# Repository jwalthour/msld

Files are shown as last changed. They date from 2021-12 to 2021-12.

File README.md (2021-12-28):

# Multi-Sport LED display

## Credits
A huge thanks to the following:
* ESPN.com for making an openly accessible sports data API that enables all these projects
* Github user mikemountain for NFL support and my original inspiration: https://github.com/mikemountain/nfl-led-scoreboard
* Github user riffnshred on whose work mikemountain's was based: https://github.com/riffnshred/nhl-led-scoreboard
* Github developers who wrote the MLB LED scoreboard on which all the above are based: https://github.com/MLB-LED-Scoreboard/mlb-led-scoreboard
* Github user hzeller for the RGB matrix driver: https://github.com/hzeller/rpi-rgb-led-matrix/

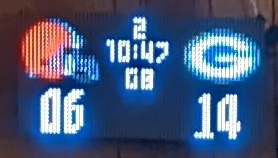
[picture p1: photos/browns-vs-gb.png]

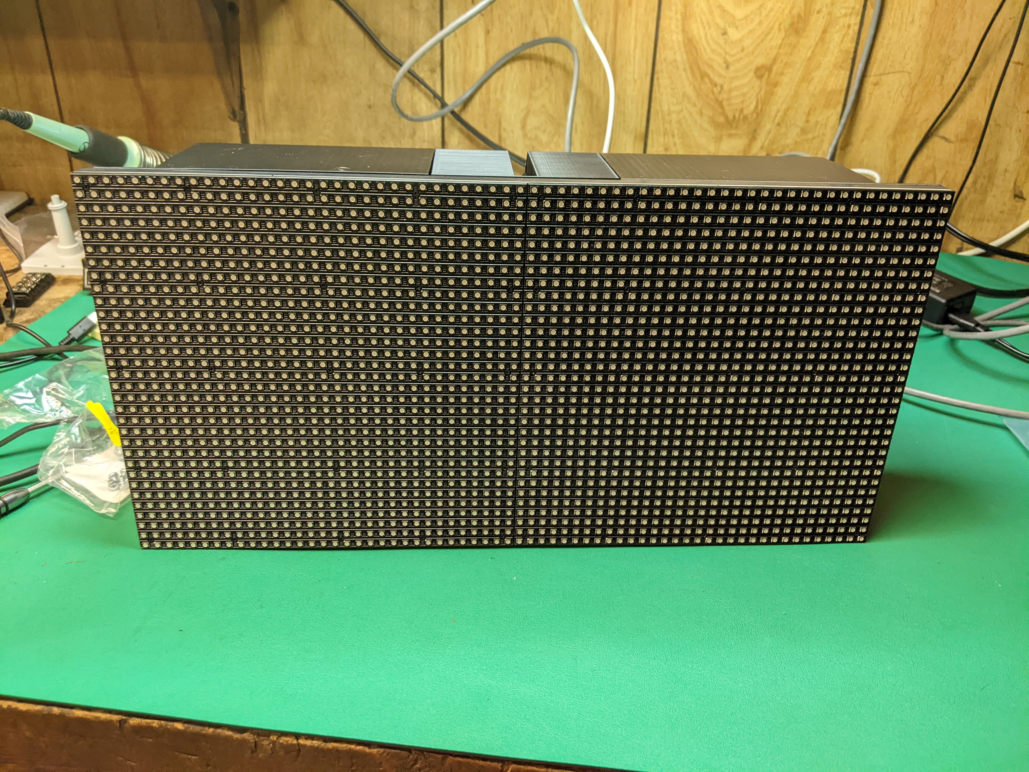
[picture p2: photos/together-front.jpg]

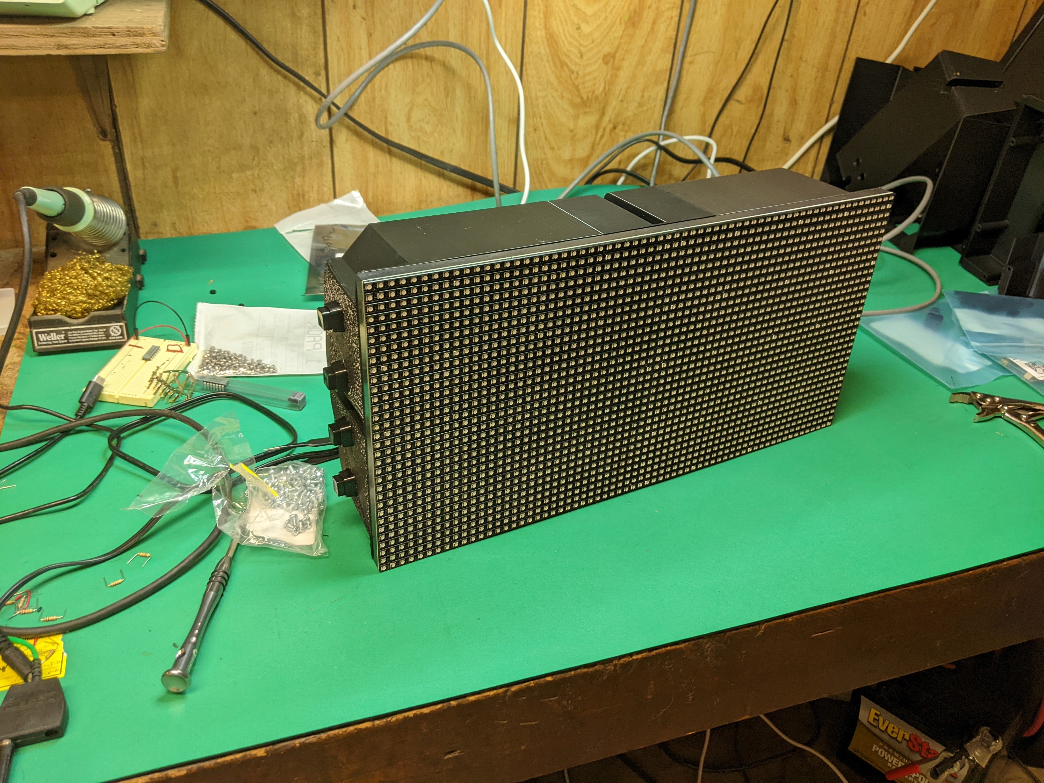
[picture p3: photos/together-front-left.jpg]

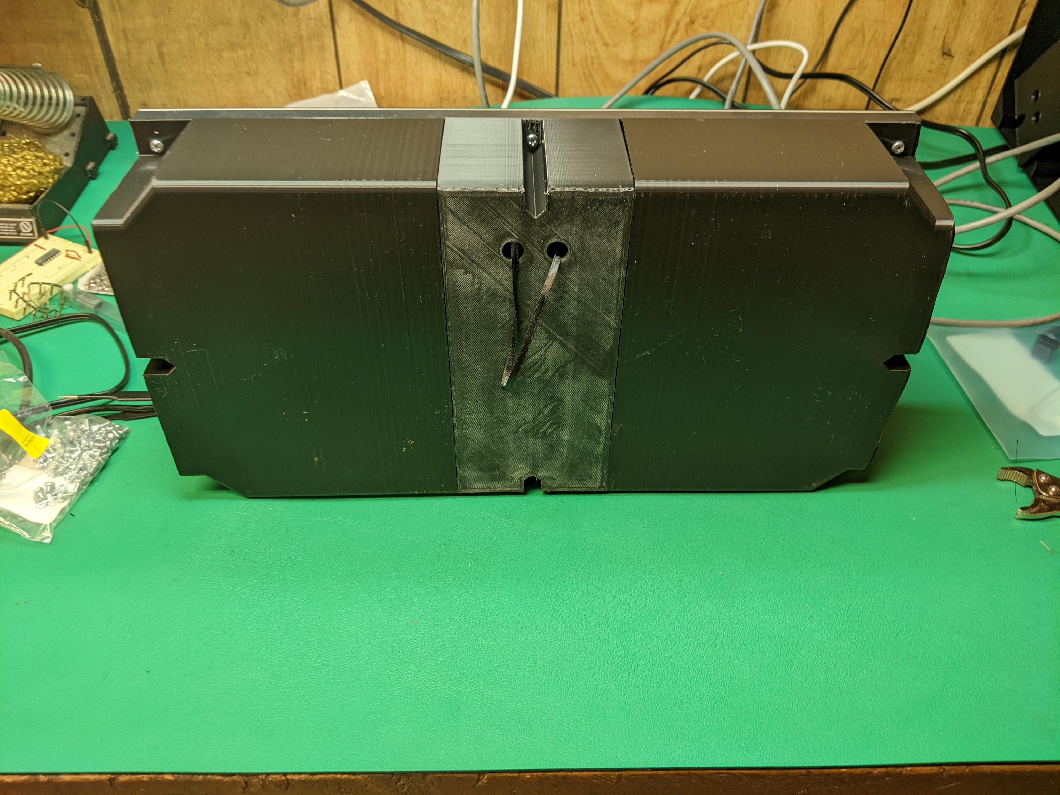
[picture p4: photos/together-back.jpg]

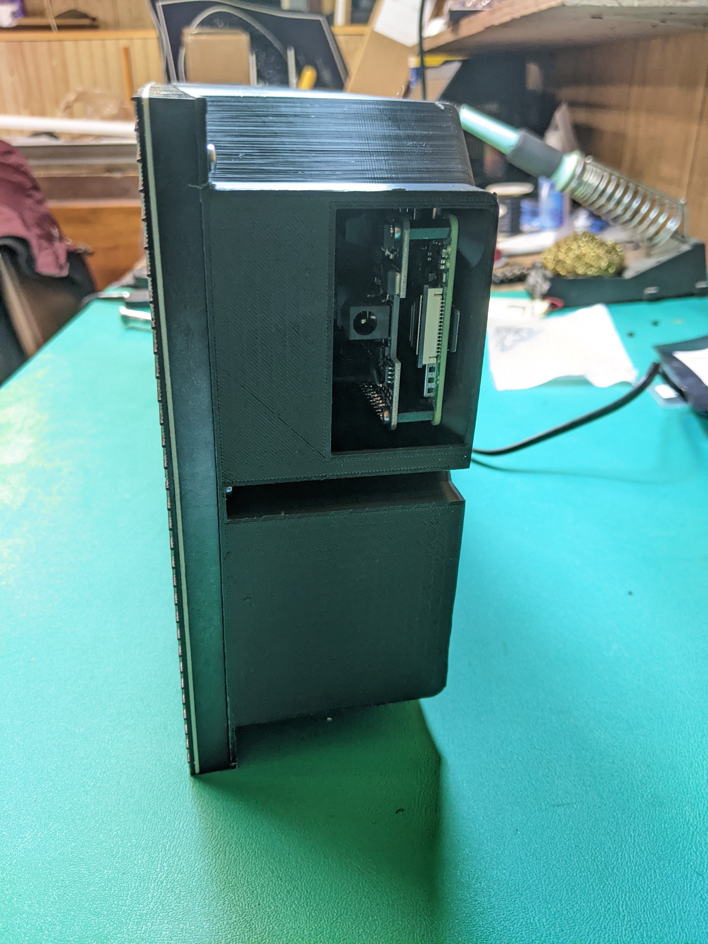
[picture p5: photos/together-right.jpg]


## How to build your own

[Electrical](electrical/Electrical.md)

[Mechanical](mechanical/Mechanical.md)

[Software](Installation.md)

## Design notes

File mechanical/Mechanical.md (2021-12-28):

# Printing and assembly

## Printing

The backshell prints in three parts: left, right, and center.  These are from the viewer's perspective - "left" has the button holes, "right" has the Pi.  STL files for all three are found in this directory.

Print settings I used common to all three parts:
* PLA
* 0.4mm nozzle
* 1.05mm wall thickness (maybe do thicker - it's important for the threaded inserts to grab onto something)
* 40% infill, gyroid (made this higher than default to strengthen the parts)
* 6 top layers, 6 bottom layers
* Brim adhesion
* Coasting off
* 200°C extruder
* 60°C bed
* 15mm/s initial speed
* 50mm/s final speed

Print the left and right sides with no supports, and their alignment pins facing upward.  You won't be able to remove supports from the holes for the threaded inserts, so definitely do not use supports.

The screenshot below shows both the left and right sides together as one print.  I don't recommend this, as it adds about a day to the overall printing.

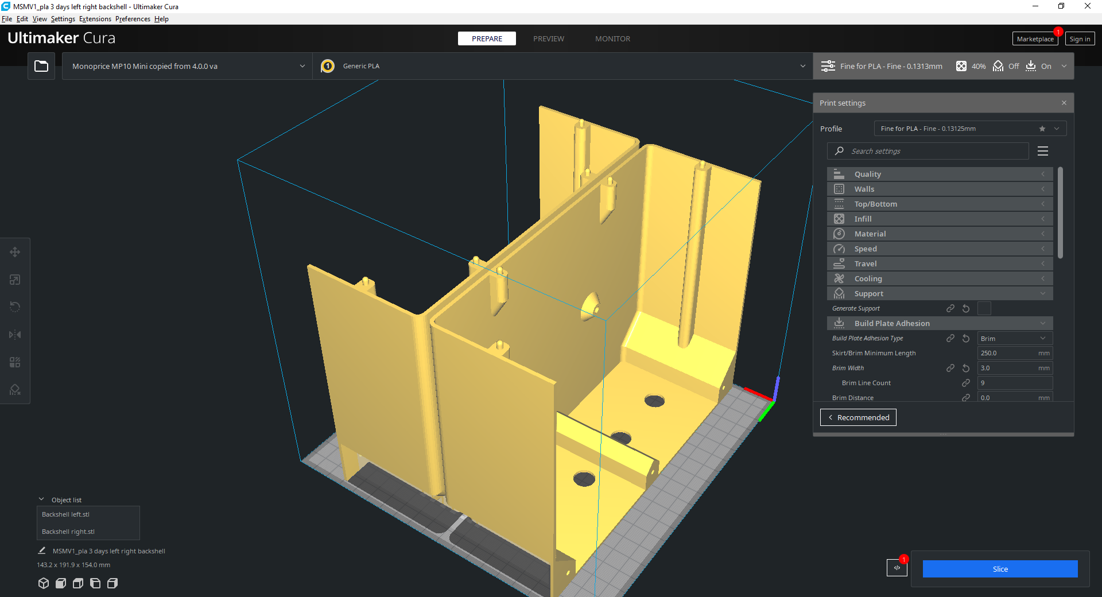
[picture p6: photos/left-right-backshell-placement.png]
left and right backshell orientation


1. Print the center side with supports on and the large rib upward (the "inside" up).

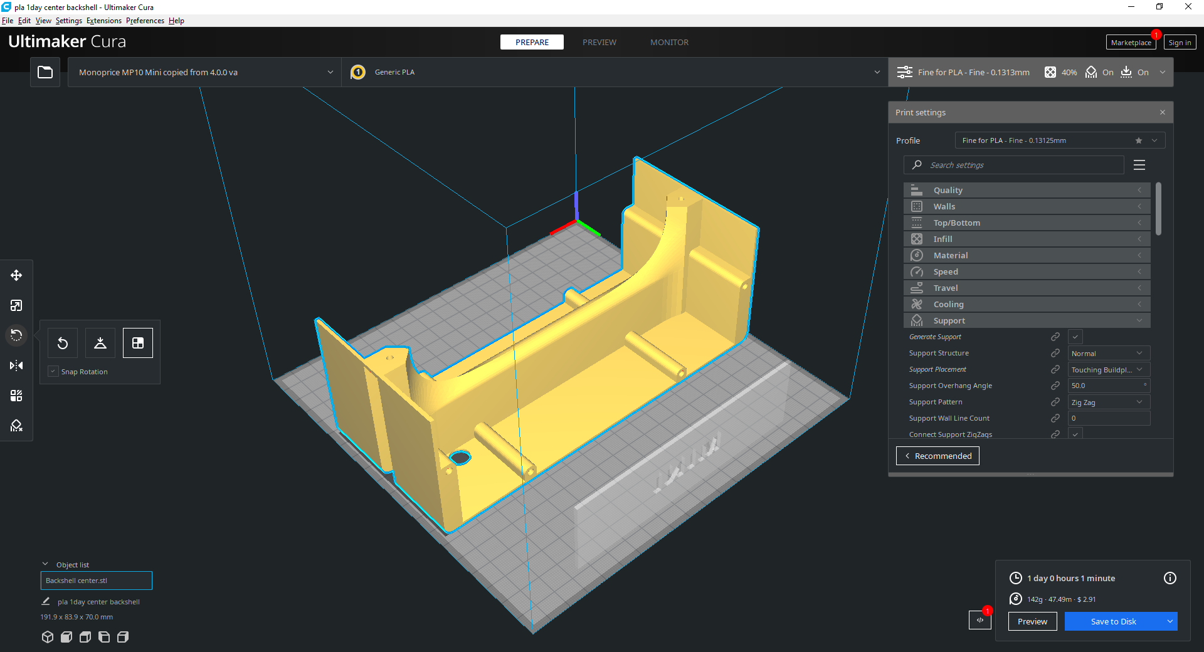
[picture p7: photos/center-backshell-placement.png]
center backshell orientation


Each of the parts is about a 1 day print.

## Assembly

Install the threaded inserts by setting your soldering iron to about 400°F and gently melting them down in.  You need 4 for the pi and 2 for the perma proto board.

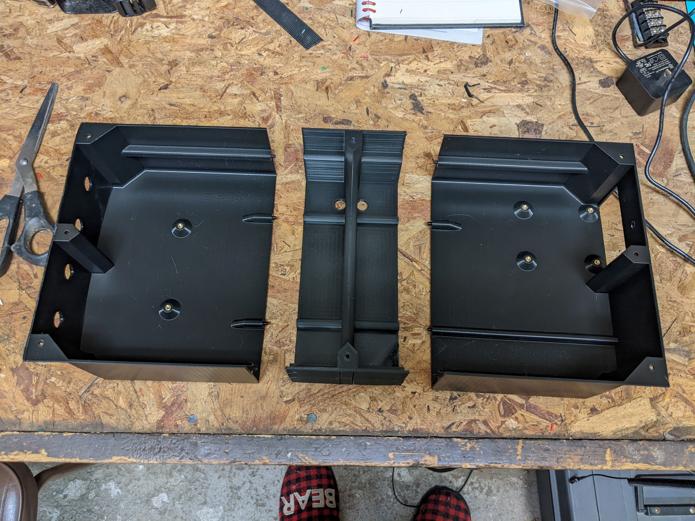
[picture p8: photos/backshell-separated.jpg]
Backshell after installing threaded inserts


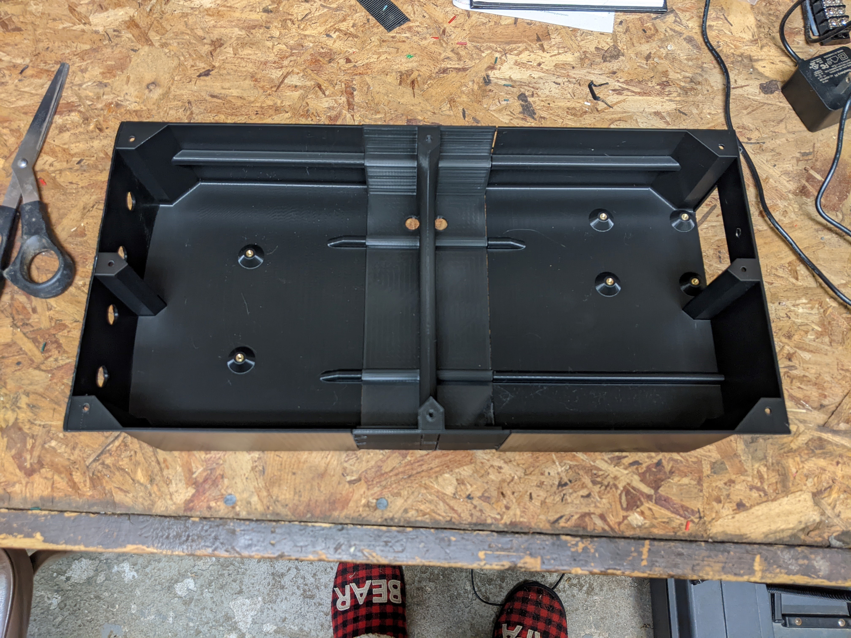
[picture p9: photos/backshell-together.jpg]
Backshell fit together


If you want to hang the display on the wall, tie about a 6" length of ribbon (or string, or wire) through the holes in the center piece.

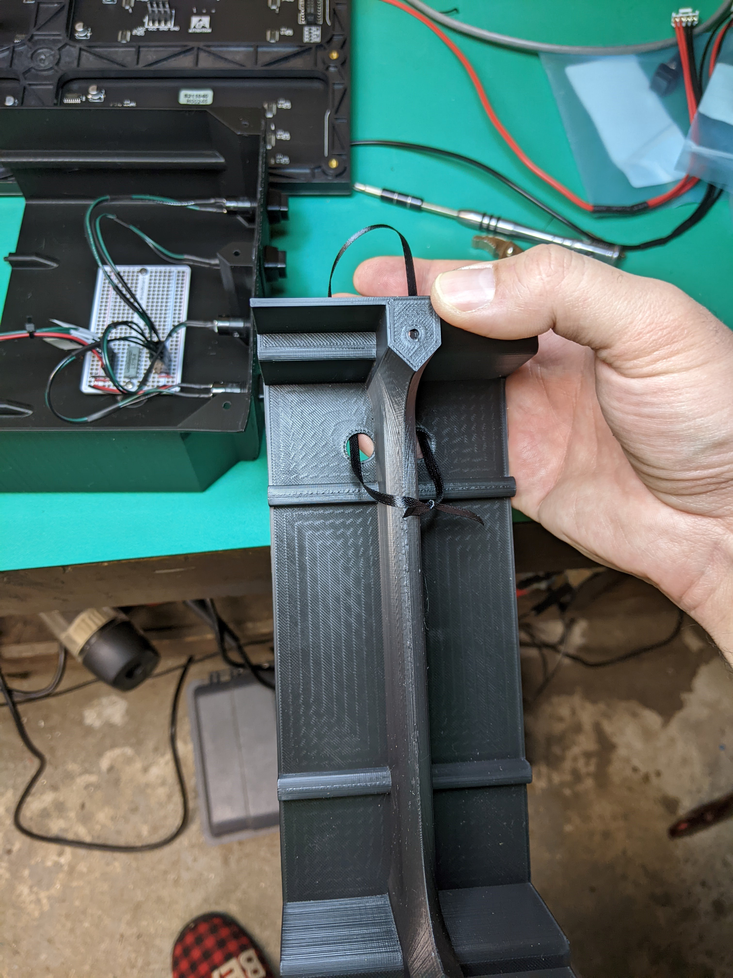
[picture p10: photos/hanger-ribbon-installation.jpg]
Hanger ribbon


Perform all soldering (see electrical notes) prior to assembly.

Place Pi, screw down with 4 standoffs

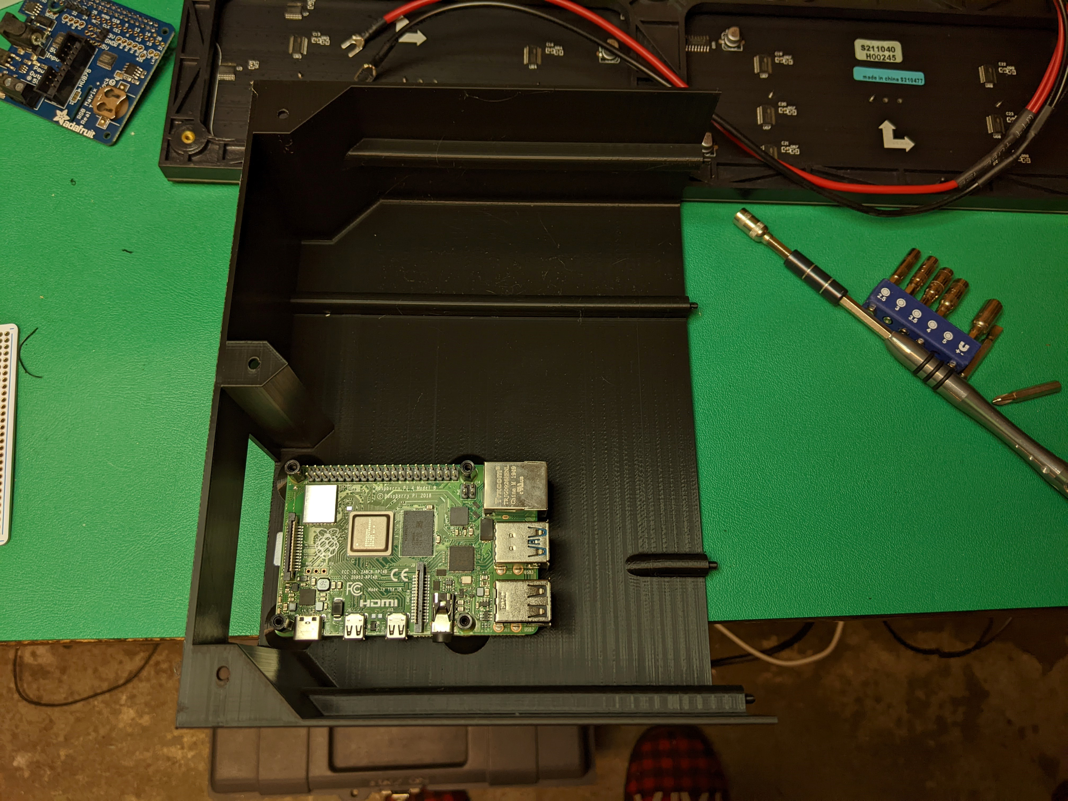
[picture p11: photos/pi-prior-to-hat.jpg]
Pi without hat


Place Pi Hat, screw down with 4 M2.5 screws. Install coin cell battery. (Note this photo shows some header pins in the wrong place)

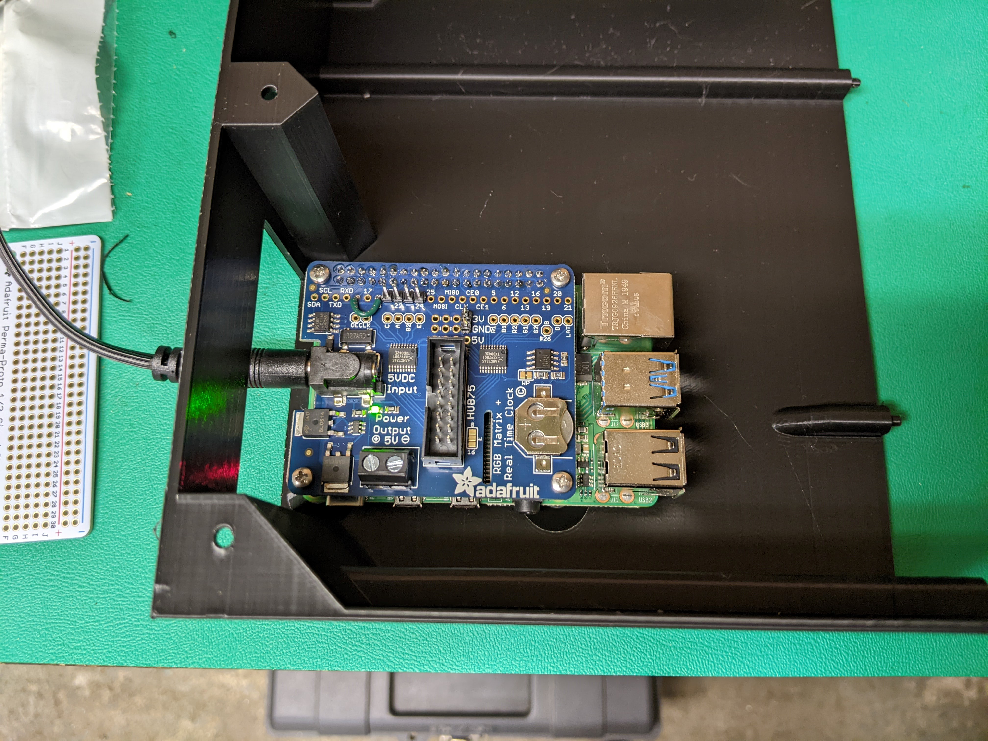
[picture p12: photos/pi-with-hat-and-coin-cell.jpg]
Pi with hat


Install perma proto board.  Install buttons and connect them.

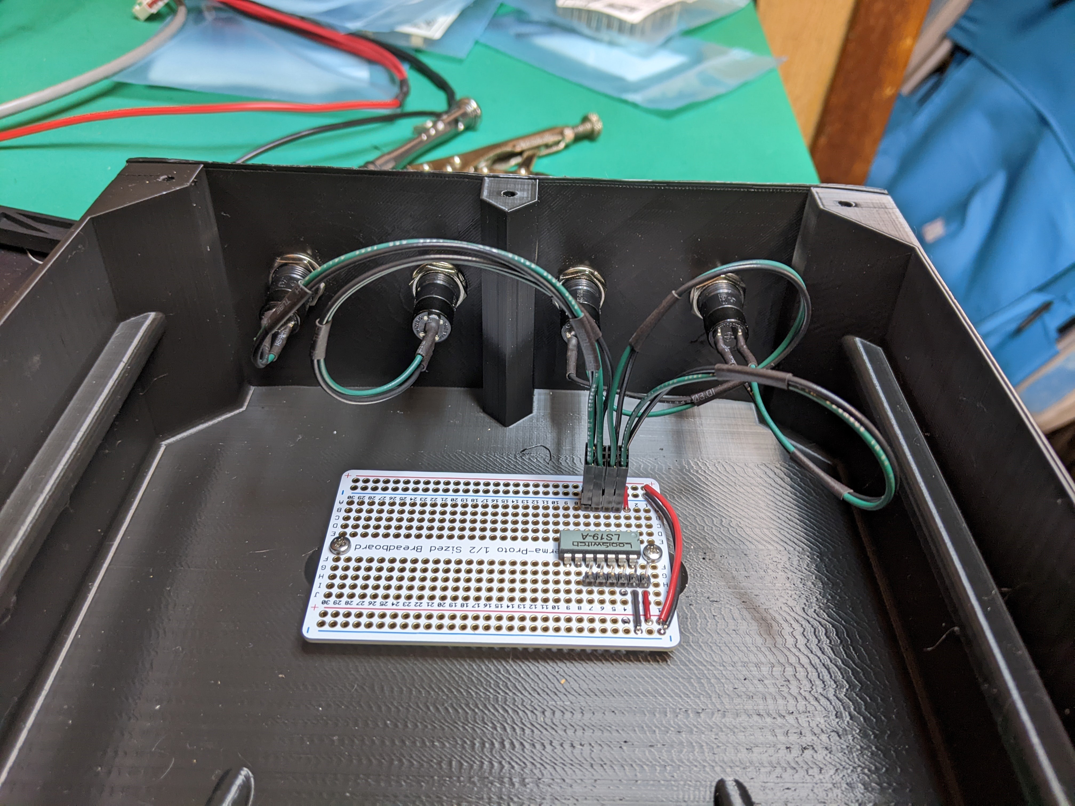
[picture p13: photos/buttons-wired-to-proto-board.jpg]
Wired buttons


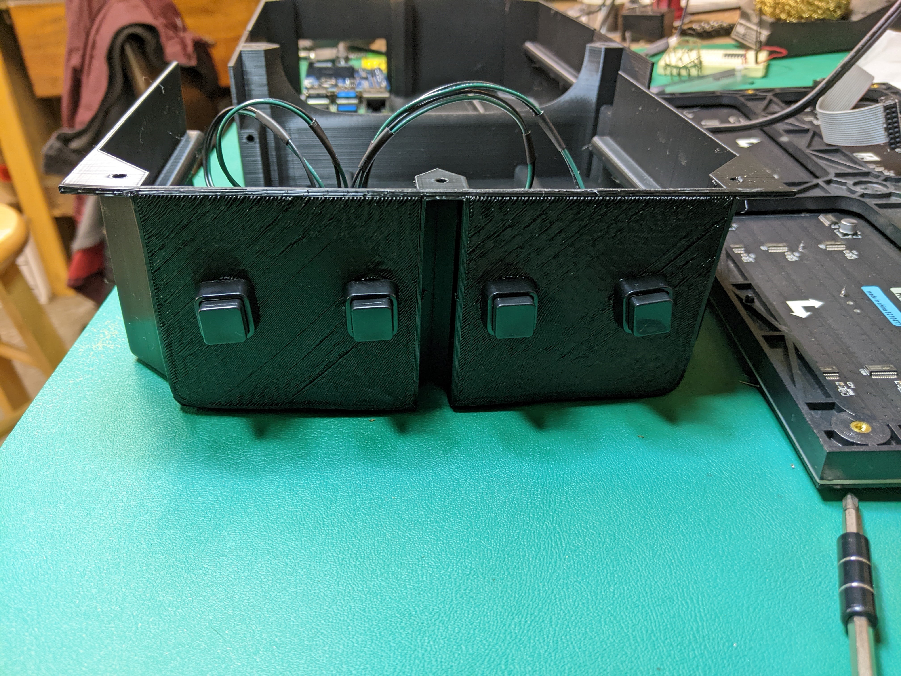
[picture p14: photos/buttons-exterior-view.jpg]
Buttons


Connect all wiring (you'll need to have the backshell close to the LED panel to do this.  Use a wire anchor and zipties to keep wires from rattling around too much.

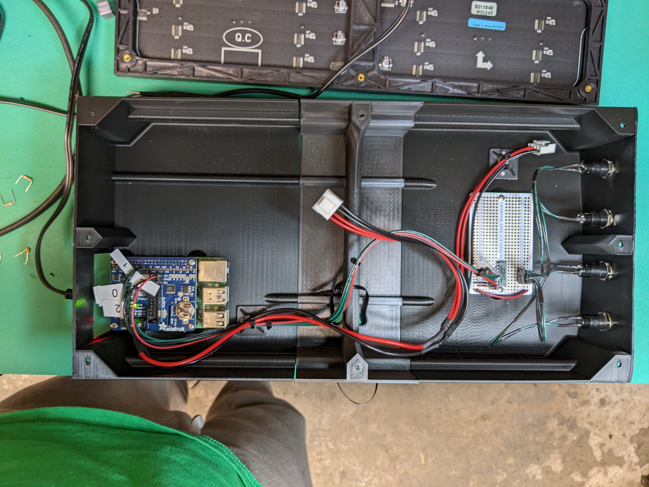
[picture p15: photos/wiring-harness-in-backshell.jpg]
Wiring harness


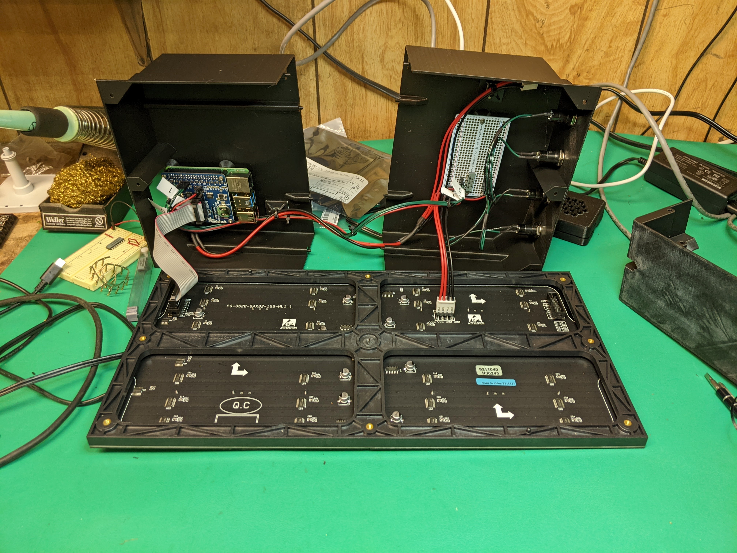
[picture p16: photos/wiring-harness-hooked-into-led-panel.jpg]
wiring harness hooked into led panel


Use M3 screws to secure the backshell.  The alignment pins will only loosely fit - they won't grip each other.  The screws are required to keep things from sliding around.

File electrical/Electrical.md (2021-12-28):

# Soldering and wiring

## Pi hat

1. Solder a short wire between GPIO pins 4 and 18 (Directions from here: https://github.com/hzeller/rpi-rgb-led-matrix/tree/6668ff8b55fcfe5ea36cf22aa48155c9ced177a9#improving-flicker)
1. Solder a male header pin onto each of these GPIO pins for the buttons: [14,15,25,19]
1. Solder a male header pin onto a 3.3V pin and to a GND pin

Should look like this when done:

Pi hat, modified

## Adafruit perma proto board

1. Solder debounce chip as shown in the image below.  Inputs go to a header on one side, outputs and power in on the other.

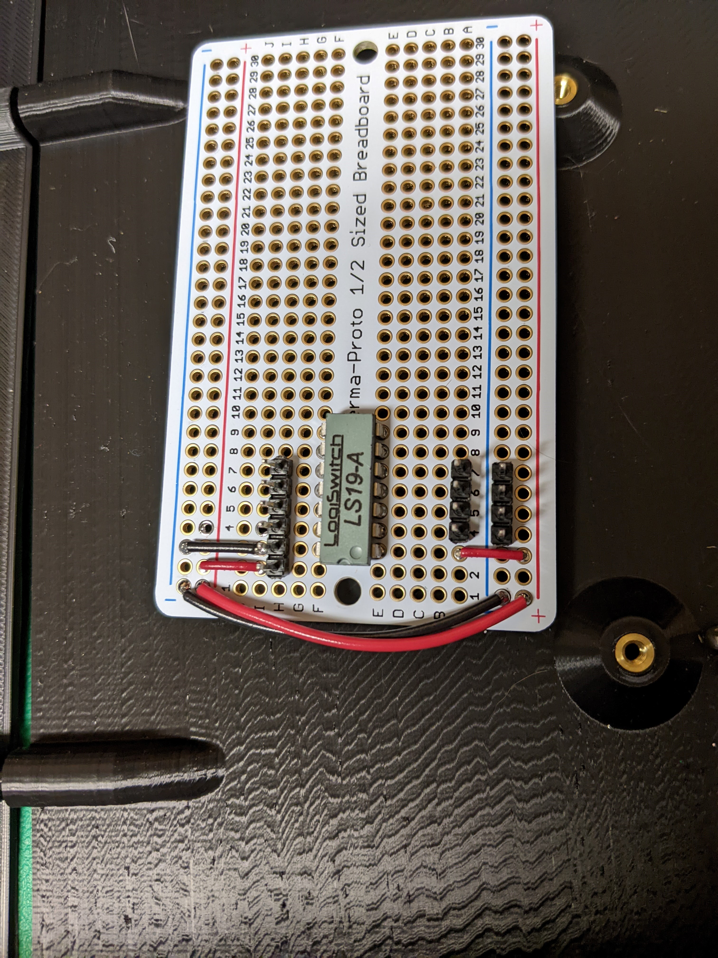
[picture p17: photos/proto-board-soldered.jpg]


## Buttons

Note: I used green for signal wires.  Use whatever color you want; I'm not your boss.

1. Cut a green and black wire for each button - about 5" long each.
1. Solder one of each color wire to each button, and cover terminals with heatshrink.
1. Crimp a rectangular header socket contact to each wire, and slide into pins 1 and 3 of a 3-position housing.  This will allow the buttons to connect between the ground and signal headers on the proto board.

Buttons connected

Buttons, exterior view

## Debouncer-to-Pi-hat cable

1. This cable is about 2 feet long to allow it to be secured to the backshell. It's 4 signal conductors, one ground, one 3.3V.  So 1 red, 1 black, and 4 green.
1. Crimp a rectangular header socket contact to each end of each wire
1. On one end, use either a 6 position housing or qty2 3position housings.  See image of proto board.
1. The other end has to go to a bunch of different places on the pi hat.  I just wrapped each contact in heatshrink.

Buttons, exterior view

## LED panel power cable

The kit from Adafruit for me came with a cable with spade connectors.  I don't like to have that much exposed energized conductor surface.  So I cut off half of each spade, removed the old heatshrink, and added new heatshrink that went further along the spade.  I also bent each spade.  You could also buy ferrules and re-crimp.

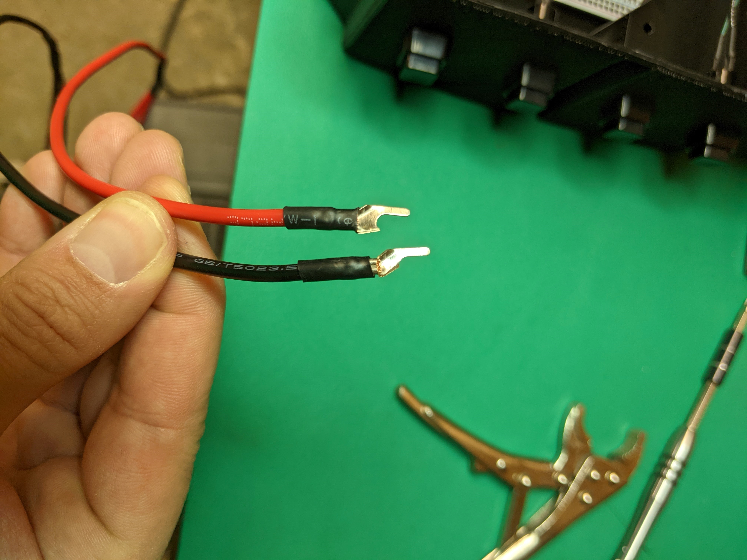
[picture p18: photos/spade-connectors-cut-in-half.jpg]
Spades before heatshrink


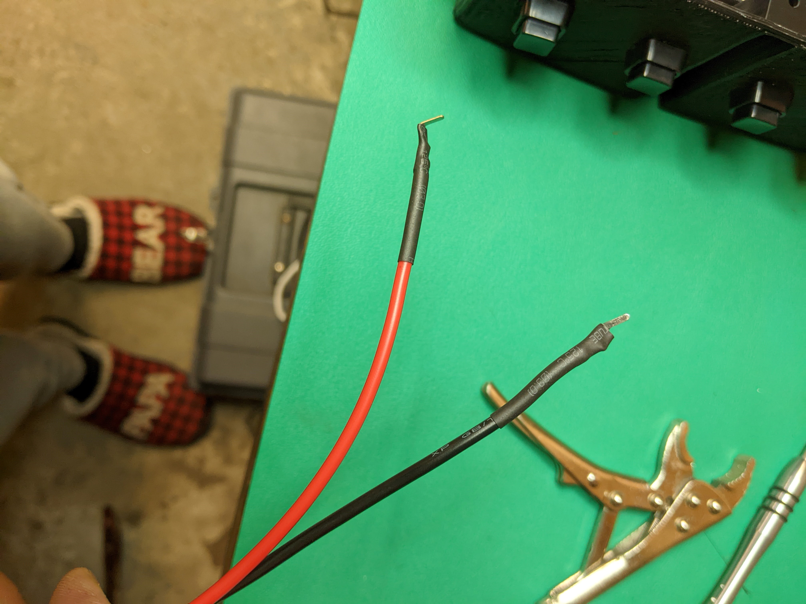
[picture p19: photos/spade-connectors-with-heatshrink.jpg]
Spades after heatshrink


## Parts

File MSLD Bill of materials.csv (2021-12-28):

Description | Source | PN | Link | Qty required | Notes
Debouncer | Digi-key | 2978-LS19-P-ND | https://www.digikey.com/en/products/detail/logiswitch/LS19-P/13540840 | 1
Pins | Digi-key | WM50014-36-ND | https://www.digikey.com/en/products/detail/molex/0022284360/313821 | 1
Housings | Digi-key | 952-2228-ND | https://www.digikey.com/en/products/detail/harwin-inc/M20-1060300/3728192 | 4
Contacts | Digi-key | 952-2157-1-ND | https://www.digikey.com/en/products/detail/harwin-inc/M20-1160042/3728123 | 12 | Don't be dumb, buy a 100pk
Buttons | Digi-key | EG2001-ND | https://www.digikey.com/en/products/detail/e-switch/PS1023ABLK/82862 | 4
Raspberry Pi Model 4B |  |  |  | 1 | Any RAM size
RGB Matrix HAT + RTC for Raspberry Pi - Mini Kit | Adafruit | 2345 | https://www.adafruit.com/product/2345 | 1
CR1220 12mm Diameter - 3V Lithium Coin Cell Battery | Adafruit | 380 | https://www.adafruit.com/product/380 | 1
5V 4A (4000mA) switching power supply | Adafruit | 1466 | https://www.adafruit.com/product/1466 | 1
64x32 RGB LED Matrix - 6mm pitch | Adafruit | 2276 | https://www.adafruit.com/product/2276 | 1 | STLs are sized for the 6mm pitch version
Adafruit Perma-Proto Half-sized Breadboard PCB | Adafruit | 1609 | https://www.adafruit.com/product/1609 | 1
Threaded inserts, m2.5x0.45mm | McMaster-Carr | 94180A321 | https://www.mcmaster.com/94180A321/ | 6 | Don't be dumb, buy a 100pk
Screws, M2.5 x0.45x4mm | McMaster-Carr | 92000A102 | https://www.mcmaster.com/catalog/92000A102 | 6 | Don't be dumb, buy a 100pk
Screws, M3x0.5x6mm | McMaster-Carr | 92005A116 | https://www.mcmaster.com/catalog/92005A116 | 8 | Don't be dumb, buy a 100pk
Brass M2.5 Standoffs for Pi HATs - Black Plated - Pack of 2 | Adafruit | 2336 | https://www.adafruit.com/product/2336 | 2 | For 4 total standoffs
Hookup wire, ~20AWG, red, stranded |  |  |  | about 2ft
Hookup wire, ~20AWG, black, stranded |  |  |  | about 2ft
Hookup wire, ~20AWG, green, stranded |  |  |  | about 8ft
Ribbon, about 5mm wide |  |  |  |  | Or string or something. Only required to use the hanging holes in the back.
Heatshrink
Adhesive wire anchors
Zipties

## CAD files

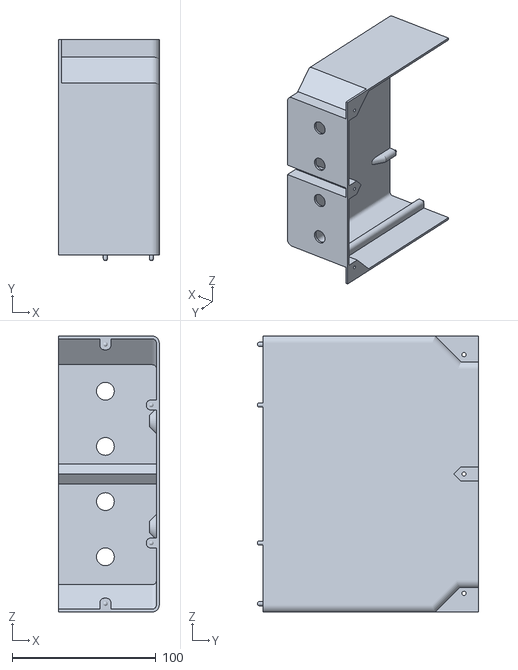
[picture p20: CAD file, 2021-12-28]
mechanical/Backshell left.stl
70.0 x 154.0 x 191.9

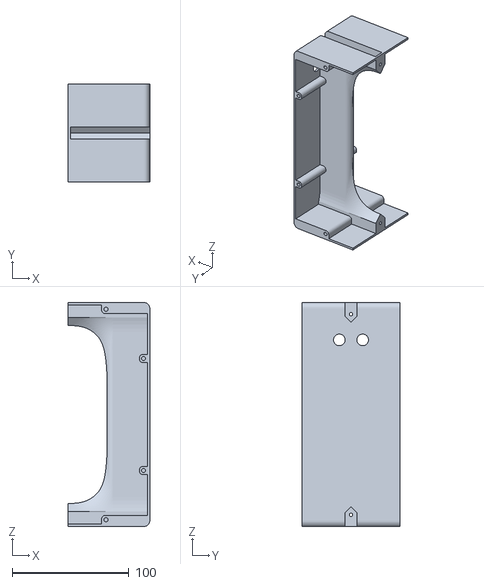
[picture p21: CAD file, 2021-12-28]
mechanical/Backshell center.stl
70.0 x 83.9 x 191.9

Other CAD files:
mechanical/Backshell right.stl
mechanical/Backshell and assembly v51.f3z

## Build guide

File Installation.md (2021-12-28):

# Software setup notes

TODO: this needs a lot of details added

* Installed python3 and uninstalled python2 prior to installing the rpi module
* These commands were used to install python3 and the rgb-led-matrix library:
````bash
sudo rm /usr/bin/python
sudo ln -s /usr/bin/python3 /usr/bin/python
ls -l /usr/bin/python*
python --version
sudo update-alternatives --install $(which python) python $(readlink -f $(which python3)) 3
sudo apt remove python2.7*
sudo apt install python3
sudo apt install python3-dev
sudo apt autoremove
ls -l /usr/bin/python*
sudo ln -s /usr/bin/python3 /usr/bin/python
# cd to rpi-rgb-led-matrix
make build-python
sudo make install-python
sudo apt install python3-pil
````

* I have some extra partitions in my Pi setup to make it easier to configure things from a Windows PC:

````bash
msld@msld:/mnt/source/msld $ lsblk
NAME        MAJ:MIN RM  SIZE RO TYPE MOUNTPOINT
mmcblk0     179:0    0 59.5G  0 disk
├─mmcblk0p1 179:1    0  256M  0 part /boot
├─mmcblk0p2 179:2    0   37G  0 part /
├─mmcblk0p3 179:3    0  954M  0 part /mnt/config
└─mmcblk0p4 179:4    0 19.6G  0 part /mnt/source
msld@msld:/mnt/source/msld $ blkid
/dev/mmcblk0p1: LABEL_FATBOOT="boot" LABEL="boot" UUID="5DE4-665C" TYPE="vfat" PARTUUID="9730496b-01"
/dev/mmcblk0p2: LABEL="rootfs" UUID="7295bbc3-bbc2-4267-9fa0-099e10ef5bf0" TYPE="ext4" PARTUUID="9730496b-02"
/dev/mmcblk0p3: LABEL_FATBOOT="CONFIG" LABEL="CONFIG" UUID="8A10-B881" TYPE="vfat" PARTUUID="9730496b-03"
/dev/mmcblk0p4: UUID="b2668c6f-837f-40c7-9606-1532f0bb9e86" TYPE="ext4" PARTUUID="9730496b-04"
msld@msld:/mnt/source/msld $ cat /etc/fstab
proc            /proc           proc    defaults          0       0
PARTUUID=9730496b-01  /boot           vfat    defaults          0       2
PARTUUID=9730496b-02  /               ext4    defaults,noatime  0       1
# a swapfile is not a swap partition, no line here
#   use  dphys-swapfile swap[on|off]  for that
UUID=8A10-B881  /mnt/config     vfat    rw,user 0       2
UUID=b2668c6f-837f-40c7-9606-1532f0bb9e86       /mnt/source     ext4    rw,user,exec    0       2
msld@msld:/mnt/source/msld $ mount
/dev/mmcblk0p2 on / type ext4 (rw,noatime)
...
/dev/mmcblk0p3 on /mnt/config type vfat (rw,nosuid,nodev,noexec,relatime,fmask=0022,dmask=0022,codepage=437,iocharset=ascii,shortname=mixed,errors=remount-ro,user)
/dev/mmcblk0p4 on /mnt/source type ext4 (rw,nosuid,nodev,relatime,user)
/dev/mmcblk0p1 on /boot type vfat (rw,relatime,fmask=0022,dmask=0022,codepage=437,iocharset=ascii,shortname=mixed,errors=remount-ro)
tmpfs on /run/user/1001 type tmpfs (rw,nosuid,nodev,relatime,size=191132k,mode=700,uid=1001,gid=1001)

````

### Prerequisites
````bash
sudo pip3 install pytz tzlocal requests
````

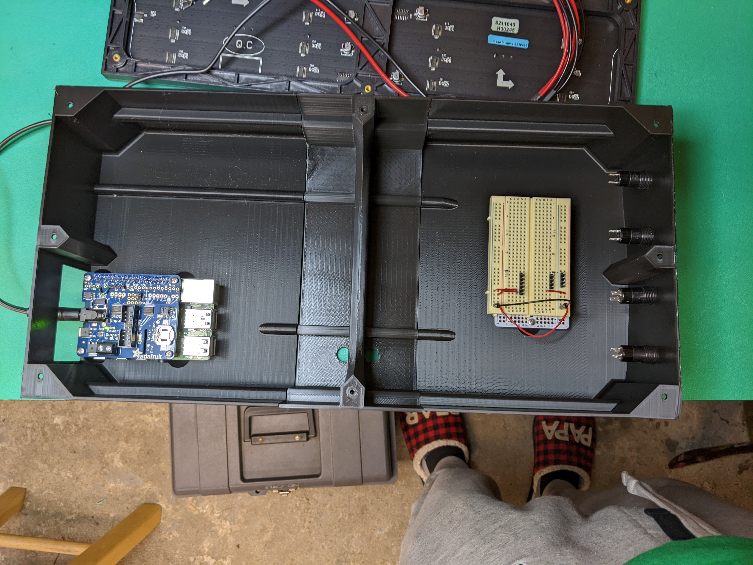
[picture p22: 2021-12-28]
photos/pi-and-proto-board-prior-to-soldering.jpg

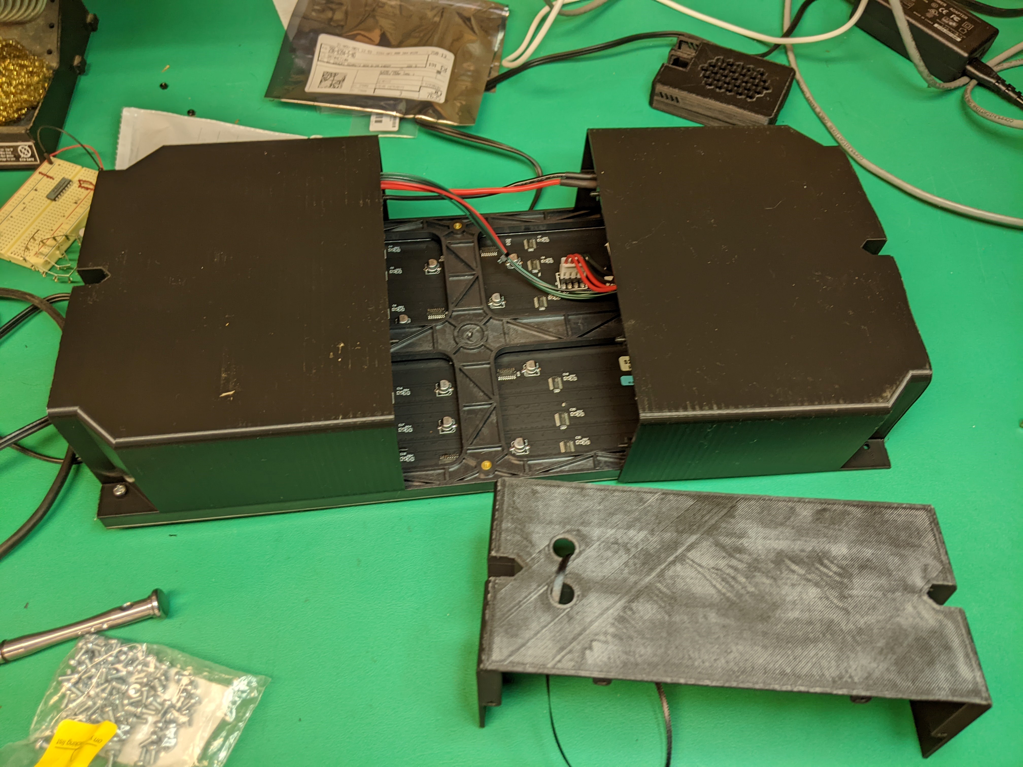
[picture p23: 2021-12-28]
photos/backshell-right half-installed.jpg

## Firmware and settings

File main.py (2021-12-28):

#!/usr/bin/python3
# -*- coding: utf-8 -*-
"""
Multi-sport LED Display entry point
"""

import argparse
import time
import logging
from rgbmatrix import RGBMatrix
from nfl.data.data import Data
from nfl.data.scoreboard_config import ScoreboardConfig as NflScoreboardConfig
from nfl.renderer.main import MainRenderer as NflMainRenderer
from nfl.utils import add_nfl_args, add_rpi_display_args, led_matrix_options
from input_listener import InputListener
import threading
from enum import Enum

logger = logging.getLogger(__name__)

BTN_NFL = 0
BTN_MLB = 1
BTN_BRIGHTER = 2
BTN_DIMMER = 3

class Sport(Enum):
    NFL = 'NFL'
    MLB = "MLB"
    NONE = 'None'

if __name__ == "__main__":
    logging.basicConfig(level=logging.INFO, datefmt="%H:%M:%S", format=" %(levelname)-8s %(asctime)s %(message)s")

    # Get supplied command line arguments
    parser = argparse.ArgumentParser()
    add_rpi_display_args(parser)
    add_nfl_args(parser)
    parser.add_argument('--stdio-btns', action='store_true')
    args = parser.parse_args()

    cur_sport: Sport = Sport.NONE
    requested_sport: Sport = Sport.NFL

    # For some reason, we get a raspberry pi GPIO error
    # if this is initialized after the RGBMatrix.
    # Everything seems happy to coexist as long as this one's started first.
    # input_listener = InputListener(args.stdio_btns)
    # def btn_pressed(btn: int) -> None:
    #     """
    #     A button was pressed
    #     btn: int, [0,3], 0 is topmost button
    #     """
    #     global requested_sport
    #     if btn == BTN_NFL:
    #         requested_sport = Sport.NFL
    #     elif btn == BTN_MLB:
    #         requested_sport = Sport.MLB
    #     btn_event.set()
    # def exit() -> None:
    #     exit_event.set()
    #     btn_event.set()
    # input_listener.btn_cb = btn_pressed
    # input_listener.exit_cb = exit
    
    # Check for led configuration arguments
    matrixOptions = led_matrix_options(args)

    # Initialize the matrix
    matrix = RGBMatrix(options = matrixOptions)
    # Initialize NFL
    nfl_config = NflScoreboardConfig("../nfl_config", args)
    nfl_data = Data(nfl_config)
    nfl_renderer = NflMainRenderer(matrix, nfl_data)

    renderers = {
        Sport.NFL:nfl_renderer
    }

    btn_event: threading.Event = threading.Event()
    exit_event: threading.Event = threading.Event()


    nfl_renderer.init()
    while not exit_event.is_set():
        if requested_sport != cur_sport:
            logger.info("Changing sport from %r to %r."%(cur_sport, requested_sport))
            renderers[requested_sport].init()
            cur_sport = requested_sport

        delay = renderers[cur_sport].retrieve_data()
        renderers[cur_sport].render()
        btn_event.wait(delay)
        if btn_event.is_set():
            btn_event.clear()

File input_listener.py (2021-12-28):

#!/usr/bin/python3
# -*- coding: utf-8 -*-
import time
import typing
import RPi.GPIO as GPIO
import readchar
import threading
import logging
logger = logging.getLogger(__name__)

GPIO.setmode(GPIO.BCM)

BCM_PIN_FOR_BTN = [14,15,25,19]
CHAR_FOR_BTN = ['a','s','d','f']


class InputListener():
    """
    Class that listens for either keystrokes on stdin or physical button presses,
    and reports either as a callback
    """
    _kt: threading.Thread = None
    exit_cb:typing.Callable[[],None] = None
    btn_cb:typing.Callable[[int], None] = None

    def __init__(self, listen_to_stdio: bool = False) -> None:
        for pin in BCM_PIN_FOR_BTN:
            GPIO.setup(pin, GPIO.IN, pull_up_down=GPIO.PUD_UP)
            GPIO.add_event_detect(pin, GPIO.FALLING, callback=self._falling_edge)
        if listen_to_stdio:
            self._kt = threading.Thread(target=self._key_listener_thread, daemon=True)
            self._kt.start()

    def _key_listener_thread(self):
        logger.info("Listening for keys")
        while True:
            input_char = readchar.readchar()
            if input_char in CHAR_FOR_BTN:
                btn = CHAR_FOR_BTN.index(input_char)
                logger.debug("Got button %d"%btn)
                if self.btn_cb != None:
                    self.btn_cb(btn)
            elif input_char == '\x03':
                logger.debug("^C")
                break
            elif input_char == '\x1a':
                logger.debug("^Z")
                break
            else:
                logger.debug("Char %r isn't a button."%input_char)
        if self.exit_cb != None:
            self.exit_cb()

    def _falling_edge(self, channel):
        logger.debug("Falling edge: %r"%channel)
        if channel in CHAR_FOR_BTN:
            btn = BCM_PIN_FOR_BTN.index(channel)
            if self.btn_cb != None:
                self.btn_cb(btn)

if __name__ == '__main__':
    logging.basicConfig(level=logging.DEBUG)

    il = InputListener()

    run = True
    def ex():
        global run
        logger.info("Exiting")
        run = False

    def btn(btn: int):
        logger.info("Got button: %d"%btn)

    il.btn_cb = btn
    il.exit_cb = ex

    while run:
        time.sleep(.1)

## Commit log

2021-12-12 draft pin tester
2021-12-16 Added actual button assignments. Confirmed working with real HW. Buttons are active low.
2021-12-18 Moved all NFL files into a subdir. Removed copy of rpi-rgb-led-matrix, which we are handling with a submodule
    [active3-rpi-hub75-adapter.kicad_pcb, active3-rpi-hub75-adapter.sch, passive-rpi-hub75-adapter.kicad_pcb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]
2021-12-19 it's icky to have files only differ by case. Also the code seems to only referece the version with a lowercase 'a'. Removed this copy.
2021-12-19 missed a few refs to files
    [main.py]
2021-12-20 Running this for some reason messes with the SSH session. And of course creashes when you try to switch to MLB. But other than those, we can pretend to switch between sports.
2021-12-23 Disabled buttons
2021-12-23 Worked at least once on reboot
    [main.py]
2021-12-28 First draft of notes, bom, figures, CAD files
    [Backshell and assembly v51.f3z, Backshell center.stl, Backshell left.stl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]
2021-12-28 More doc updates
    [MSLD Bill of materials.csv]
